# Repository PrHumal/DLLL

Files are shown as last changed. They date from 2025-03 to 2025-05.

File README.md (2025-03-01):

# Digiloogika leivalaud (DLLL)

## **Ülevaade**
**Digiloogika Leivalaud (DLLL)** on õppevahend digitaalloogika skeemide koostamiseks. Seade võimaldab visuaalselt ja praktiliselt mõista digitaalloogika põhialuseid, kasutades erinevaid loogikaelemente nagu **NOR, INV, AND, OR2, XOR4 jne**. 

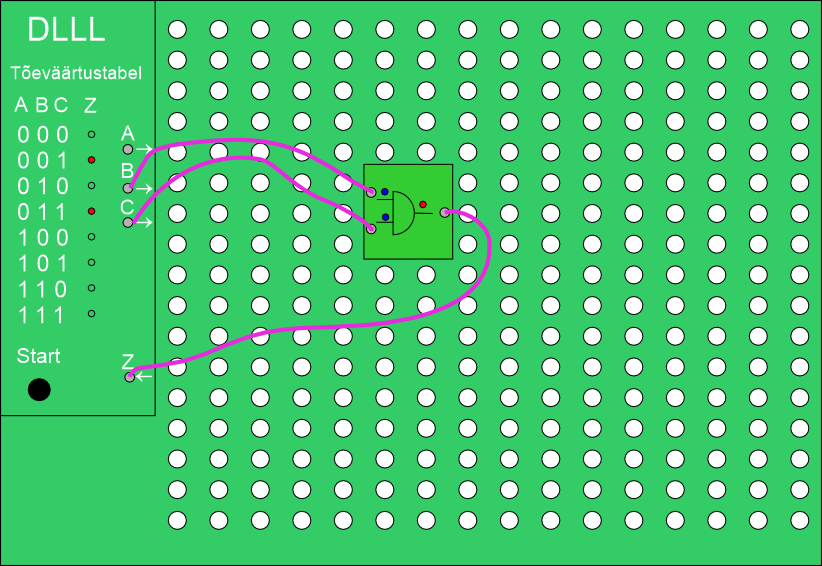
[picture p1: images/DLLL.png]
Digiloogika leivalaua pilt
  

## **Omadused**
✔ **Modulaarne disain** – loogikaelemente sisaldavad klotse saab lihtsalt vahetada.
✔ **Ülevaatlik** – loogikaelemtide klotside sisendid ja väljundid varustatud  LED indikaatoritega.
✔ **Aukudega aluslaud** – mugav ja stabiilne paigutus erinevatele elementidele.
✔ **3.5 mm patch ( [Eurorack patch](https://i0.wp.com/intellijel.com/wp-content/uploads/2023/04/cable-pack-2023-0.jpg?resize=544%2C408&ssl=1) ) kaablite ühendused** – kiire ja lihtne ühenduste loomine.
✔ **Õppevahend elektroonika ja digitaalloogika kursustele**
✔ **Edasiarnedatav** praegu on loogikaskeemi sisendiks 3 bitine tõeväärtustabeli generaator. See käib järjest kõik read läbi ning kuvab kõigile ridadele vastavad loogikaskeemie väljundi tulemused. Bittide arvu võib suurenada ning kasutada generaatorit, mis sobiks trigeritele jne.

Klotside toide ja loogika signaal peab liikuma patch kaablites läbi kahe soone. Kasutame toite reverseerimist:

✅ **ON:**  
-  **Rõngas** = **-**  
-  **Ots** = **+**  

❌ **OFF:**  
-  **Rõngas** = **+**  
-  **Ots** = **-**  

## **Kasutusala**
DLLL on mõeldud kasutamiseks **elektroonika ja digitaalloogika kursustel** ning võimaldab:
- **Praktiliselt katsetada loogikaväravate tööd.**
- **Kombineerida ja luua erinevaid digitaalseid skeeme.**
- **Arendada loogilist mõtlemist ja digitaalloogika oskusi.**

## **Projekti info**
- **Kursus:** TS.0028 Elektroonikaseadmete projekteerimine ja tootmine
- **Õppeasutus:** Eesti Maaülikool (EMÜ)
- **Õppejõud:** Dr. Heiki Lill
- **Õppeassistent:** Priit Humal

## **Paigaldus ja kasutamine**
1. Aseta vajalikud **loogikaelementide klotsid** alusele.
2. Ühenda klotsid **3.5 mm patch kaablitega** vastavalt skeemile.
3. Lülita süsteem sisse ja kontrolli loogika tööpõhimõtteid.
4. Muuda skeemi ja eksperimenteeri erinevate loogikaväravate kombinatsioonidega.

## **Failid ja dokumentatsioon**
📄 **Dlll.docx** – projekti lähteülesanne.
📄 **Skeemid/** – erinevad näidisskeemid DLLL kasutamiseks.
📄 **Juhendid/** – kasutusjuhendid ja õpetused.

## **Autorid ja kontakt**
📩 **Projekti juhendaja:** Dr. Heiki Lill (heiki.lill@emu.ee)
📩 **Õppeassistent:** Priit Humal (priit.humal@emu.ee)
📩 **Kursuse info:** [EMÜ TS.0028 Elektroonikaseadmete projekteerimine ja tootmine](https://www.emu.ee)

---
💡 **Kasulikud lingid**  
🔗 [Digitaalloogika baasteadmised](https://en.wikipedia.org/wiki/Digital_logic)  
🔗 [Elektroonikat õpetavad mänguasjad SnapCircuits](https://elenco.com/)

🚀 **Head eksperimenteerimist!**

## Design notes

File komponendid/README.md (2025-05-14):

## **Projektis kasutatavad komponendid**  

🔌 **3.5 mm pesa**  
[🛒 SJ3-35052B – Same Sky (Mouser)](https://www.mouser.ee/ProductDetail/Same-Sky/SJ3-35052B?qs=IKkN%2F947nfDmh7CCP4LptQ%3D%3D)

🔌 **Loogikaklotside kinnitus aluslauale**  
[🛒 PCB Spacer, Base Lock-In Support, Nylon 6.6, 7.1 mm x 15.9 mm](https://ee.farnell.com/tr-fastenings/trcbsb-10-01a2-rt/pcb-spacer-support-15-9mm-nylon/dp/3129014)

Eurorack patchid

[🛒 Patch kaabel (Aliexpress)](https://vi.aliexpress.com/item/32931478630.html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)

[🛒 Jagav patch kaabel (Aliexpress)](https://vi.aliexpress.com/item/1005005072699334.html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)

Väljundi juhtimise relee

https://ee.farnell.com/panasonic/tq2sa-5v/relay-signal-dpdt-30vdc-2a/dp/1124054

IM42GR.  - Eelmine relee oli otsas, kui JLCPCB-s oma parte valite siis vahetage relee selle vastu
Signal Relay, 4.5 VDC, DPDT, 2 A, IM, Surface Mount, Latching Single Coil
[1922668.pdf](https://github.com/user-attachments/files/20204832/1922668.pdf)

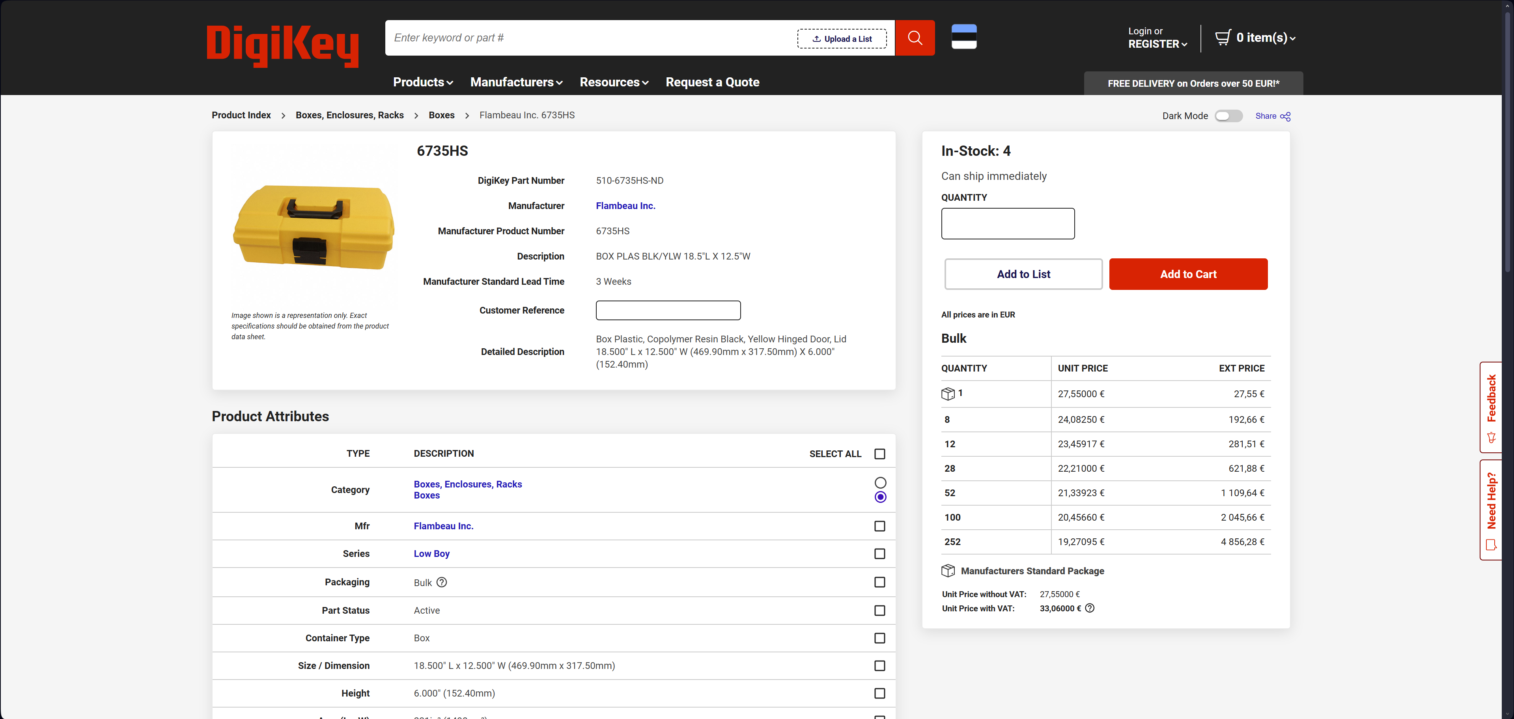
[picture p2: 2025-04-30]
komponendid/Karp 2.png

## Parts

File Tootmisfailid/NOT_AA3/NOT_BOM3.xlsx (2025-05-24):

Comment | Designator | Footprint | JLCPCB Part #（optional）
1000 | R1, R3, R5, R7, R2, R6 | RESC1608X55N | C14676
470 | R4, R8 | RESC1608X55N | C22808
G6K-2F-Y-DC12 | RL1, RL2 | F | C47190
IRF7307 | IC1, IC2 | SOIC127P600X175-8N | C5346816
SS24F | D1, D2, D3, D4, D5, D6, D7, D8 | SODFL4626X110N | C18199202
VLDS1235G | LED1, LED2 | SOD4223X297N | C499579

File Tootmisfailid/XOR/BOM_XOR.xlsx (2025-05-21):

Comment | Designator | Footprint | JLCPCB Part #
10 OHM RESISTOR | R1, R3, R5, R6 | 0603 | C22859
1000 OHM RESISTOR | R2, R4 | 0603 | C21190
220 OHM RESISTOR | R7 | 0603 | C22962
G6K-2F-Y-TR DC5 | RELEE | SMD,6.5x10mm | C47190
N CHANNEL MOSFET 50V | NFET1, NFET2, NFET3, NFET4, NFET5, NFET6 | SOT-23 | C8490
P CHANNEL MOSFET 50V | PFET1, PFET2, PFET3, PFET4, PFET5, PFET6 | SOT-23 | C504057
SS24F | D1, D2, D3, D4, D5, D6, D7, D8 | SMAF | C18199202
VLDS1235G | LED1 | SMD,2.3x2.3mm | C499579

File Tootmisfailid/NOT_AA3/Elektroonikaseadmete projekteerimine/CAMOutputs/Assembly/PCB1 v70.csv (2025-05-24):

Qty | Value | Device | Package | Parts | Description | ARROW_PART_NUMBER | ARROW_PRICE-STOCK | DESCRIPTION | HEIGHT | MANUFACTURER_NAME | MANUFACTURER_PART_NUMBER | MOUSER_PART_NUMBER | MOUSER_PRICE-STOCK | POPULARITY
8 |  | SMD5 | SMD2,54-5,08 | S1.1, S1.2, S2.1, S2.2, V1.1, V1.2, V2.1, V2.2 | SMD PAD |  |  |  |  |  |  |  |  | 21
4 | 100 | 0603WAF4701T5E | RESC1608X55N | R1, R3, R5, R7 | Chip Resistor - Surface Mount 4.7KOhms +/-1% 1/10W 0603 RoHS |  |  | Chip Resistor - Surface Mount 4.7KOhms +/-1% 1/10W 0603 RoHS | 0.55mm | UNI-ROYAL(Uniroyal Elec) | 0603WAF4701T5E
2 | 1000 | 0603WAF4701T5E | RESC1608X55N | R2, R6 | Chip Resistor - Surface Mount 4.7KOhms +/-1% 1/10W 0603 RoHS |  |  | Chip Resistor - Surface Mount 4.7KOhms +/-1% 1/10W 0603 RoHS | 0.55mm | UNI-ROYAL(Uniroyal Elec) | 0603WAF4701T5E
2 | 470 | 0603WAF4701T5E | RESC1608X55N | R4, R8 | Chip Resistor - Surface Mount 4.7KOhms +/-1% 1/10W 0603 RoHS |  |  | Chip Resistor - Surface Mount 4.7KOhms +/-1% 1/10W 0603 RoHS | 0.55mm | UNI-ROYAL(Uniroyal Elec) | 0603WAF4701T5E
2 | G6K-2F-Y-DC12 | G6K-2F-Y-DC12 | F | RL1, RL2 | OMRON Subminiature low power relay - DPDT
2 | IRF7307 | IRF7307 | SOIC127P600X175-8N | IC1, IC2 | Power MOSFET |  |  | Power MOSFET | 1.75mm | Infineon | IRF7307
8 | SS24F | SS24F | SODFL4626X110N | D1, D2, D3, D4, D5, D6, D7, D8 | 40V 550mV2A 2A SMAF Schottky Barrier Diodes (SBD) ROHS |  |  | 40V 550mV2A 2A SMAF Schottky Barrier Diodes (SBD) ROHS | 1.1mm | Shikues | SS24F
2 | VLDS1235G | VLDS1235G | SOD4223X297N | LED1, LED2 | VISHAY - VLDS1235G - LED, RED, 11CD, 630NM, SMD | VLDS1235G | https://www.arrow.com/en/products/vlds1235g/vishay | VISHAY - VLDS1235G - LED | RED | 11CD | 630NM | SMD | 2.97mm | Vishay

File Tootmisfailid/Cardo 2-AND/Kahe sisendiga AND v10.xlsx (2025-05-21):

Comment | Footprint | Design | Veerg1
1000 | RESC1608X55N | R2, R4 | C14676
470 | RESC1608X55N | R1, R3 | C23179
G6K-2F-Y-DC12 | F | RL3 | C2153162
NMOSFET_SOT23-GSD | SOT23 | Q4, Q5, Q6 | C8490
PMOSFET_SOT23-GSD | SOT23 | Q1, Q2, Q3 | C504057
SS24F | SODFL4626X110N | D1, D2, D3, D4, D5, D6, D7, D16 | C64881
VLDS1235G | SOD4223X297N | S1_LED1 | C499579

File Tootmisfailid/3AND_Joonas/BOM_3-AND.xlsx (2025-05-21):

Comment | Designator | Footprint | JLCPCB Part #（optional）
SS24F | D1,D2,D3,D4,D5,D6,D7 | SODFL4626X110N | C18199202
 | D8,D9,D10,D11,D12
NMOSFET_SOT23-GSD | NFET1,NFET2,NFET3,NFET4 | SOT23 | C8490
PMOSFET_SOT23-GSD | PFET1,PFET2,PFET3,PFET4 | SOT23 | C504057
0603WAF1001T5E | R2,R3,R7 | RESC1608X55N | 0603WAF1001T5E
0603WAJ0221T5E | R1,R4,R5 | RESC1608X55N | 0603WAJ0221T5E
C499579 | S1_LED1, S1_LED2 | SOD4223X297N | C499579
G6K-2F-Y-DC12 | RL3 | F | C47190

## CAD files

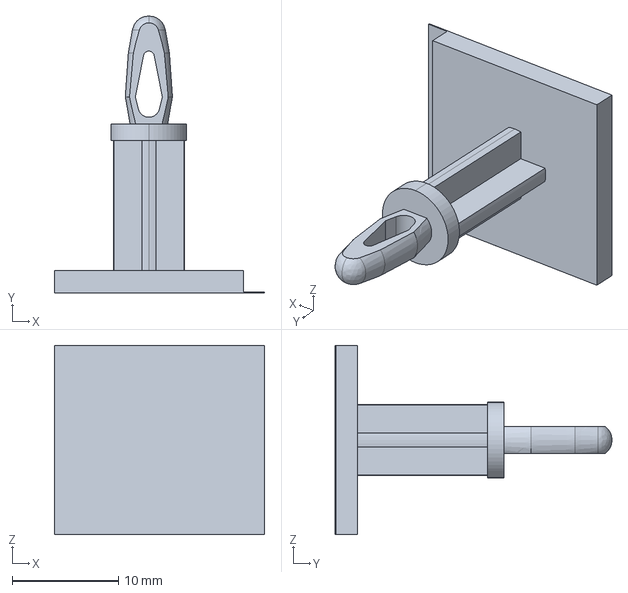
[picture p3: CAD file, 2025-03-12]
komponendid/Loogikaklotside kinnitus aluslauale.stp
19.8 x 26.1 x 17.8 mm

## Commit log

2025-04-16 Update and rename VLDS1235G.lbr to LED_VLDS1235G.lbr
2025-05-21 Tanel 2 OR
    [BOM_Tanel.xlsx, JLCSMT_Tanel1.xlsx]
2025-05-23 Tanel 2OR
    [BOM_Tanel.xlsx, JLCSMT_Tanel1.xlsx]
